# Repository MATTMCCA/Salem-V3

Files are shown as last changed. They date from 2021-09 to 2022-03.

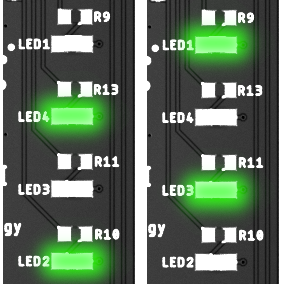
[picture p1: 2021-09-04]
Manual/masters/pics/error_state.png

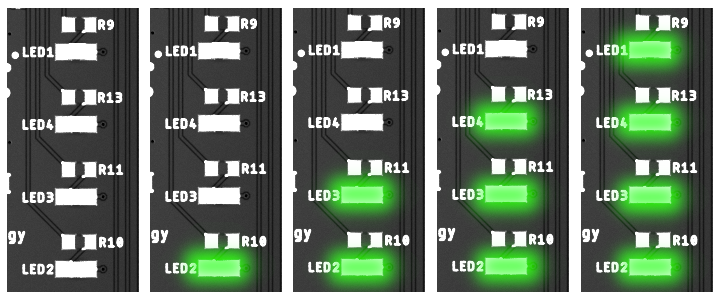
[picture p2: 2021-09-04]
Manual/masters/pics/led_bat.png

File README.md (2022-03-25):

# Salem Version 3

Third Revision of Salem, Capacitive Proximity Sensor.

https://youtu.be/Kz70OKQegTU

---

### Salem was originally designed as a REM Pod competitor. A conscience and lack of follow-though drove me to release the project, for the betterment of *Parapsychology Research*.

(Plus I didn't feel like dealing with *FCC Regulatory Compliance*.... or shipping logistics, customers, pricing, manufacturing, overhead... )

Effective range, depending on placement can vary from 6-10 inches. This is a ballpark estimate from lab testing. I have not had time to carry out a conclusive test to gauge the effective sensing range.

---

### Info

This project is a battery powered capacitive proximity sensor. Some folks believe a device like this will detect paranormal apparitions. **I can not confirm or deny the existence of ghosts. I am also not claiming this device will detect paranormal apparitions, this includes but is not limited too.**

- The Jersey Devil
- The Headless Body of Spiro Agnew
- Ghost
- Demons / Angles
- Batman
- Karma
- UFO's / USO's
- The Chupacabra
- Vampires
- Witches / Wizards
- The SOB that ate my Twix
- Bigfoot / Yeti's
- Tom Cruise
- Most Breads of Cats.
- Bloody Mary
- Unicorns
- Other Benign and Nefarious Mythical Creatures

However devices like this do exist on the market, and consumers use them in an effort to detect the "paranormal".

In full transparency, both the hardware and firmware are included in this repo. Should an individual wish to understand the operation of this device and similar devices, all necessary information is provided.

### Operation Note:

[Further Readings A](https://www.allaboutcircuits.com/technical-articles/introduction-to-capacitive-touch-sensing)

[Further Readings B](https://www.clippercontrols.com/pages/Dielectric-Constant-Values.html)

**I offer no support for this device, it has become a leisurely project.**

---

This project has been added to the hackaday [halloween hackfest](https://hackaday.com/2021/08/10/new-contest-halloween-hackfest/)

### Borrowed works maintain original license.

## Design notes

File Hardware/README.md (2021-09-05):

# Hardware Assembly 

The following items were purchased to aid in physical assembly.

- [Mounting Tape](https://www.amazon.com/gp/product/B0888DKR92)
- [Stainless Steel Internal Tooth Star Lock Washers](https://www.amazon.com/gp/product/B0794YF3QP/)
- [M3 Stainless Steel 304 Hex Socket Head Cap Bolt](https://www.amazon.com/gp/product/B07VNDFYNQ/)

## Assembly Notes

- `40mm` of `0.5mm x 24mm` mounting tape was used to adhere the battery pack onto the PCB before soldering the battery pack leads.
- `1 M3, lock washer` was placed on the antenna pad
- `1 M3, 5mm bolt` was passed though the lock washer, though the PCB, and screwed into the taped `M3 antenna`.

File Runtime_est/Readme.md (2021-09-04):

# Battery Life

| State | Current Draw | Supply voltage  |
| --- | --- | --- |
| Active | 4.38mA | 3.3v |
| Idle | 0.53mA | 3.3v |

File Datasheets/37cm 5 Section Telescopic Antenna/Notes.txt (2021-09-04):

1Pc 37cm 5 Section Telescopic Stainless Steel AM FM Radio Universal Antenna

Product Name : Telescopic Antenna;
Sections : 5 Sections
Unstretched Size : 105mm ";
Full Length : 354mm
Hole Diameter : 3mm
Material : Stainless Steel, Brass;Color : Silver Tone
4 sections telescopic antenna aerial.

Mainly used in television, radio, electric toy, remote control, lamps and lanterns, 
VCD, and other special configuration communications antenna and iron and tools 
antenna and other electronics products.

Great replacement for your damaged TV antenna or FM radio antenna.

Package Content : 1 x Telescopic Antenna

Note:
Light shooting and different displays may cause the color of the item in the
 picture a little different from the real thing. The measurement allowed error is +/- 1-3cm.

StoreFront: https://www.aliexpress.com/item/1005002545144839.html

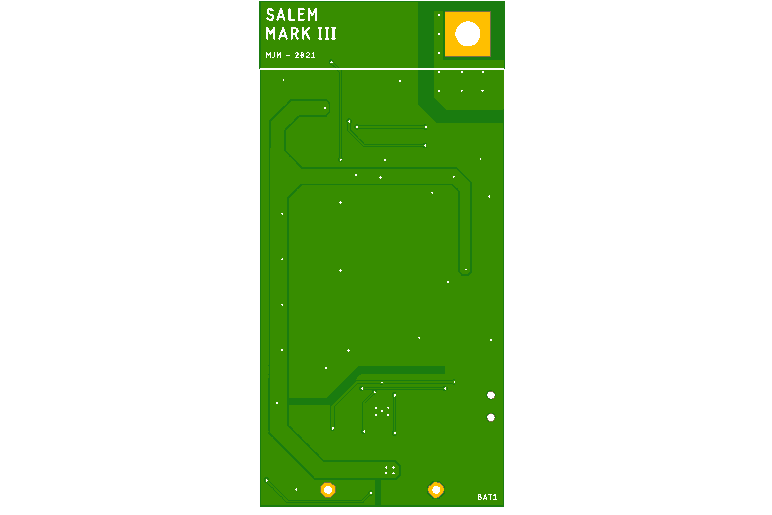
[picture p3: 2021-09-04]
Hardware/SV3/board/SV3_bot.png

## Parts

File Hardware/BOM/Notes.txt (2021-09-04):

See Digikey List for a more comprehensive PartsList.

Currently Private

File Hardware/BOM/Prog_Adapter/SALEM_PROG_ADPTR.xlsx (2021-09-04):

Index | Manufacturer Part Number | Manufacturer Name | Description | Availability | Stock Status | Customer Reference | Reference Designator | Requested Quantity 1 | Pack Quantity 1 | Pack Type 1 | Digi-Key Part Number 1 | Unit Price 1 | Extended Price 1 | Minimum Order Quantity 1 | Requested Part Number | Part Status | Original Part numbers
1 | 0532610671 | Molex | CONN HEADER SMD R/A 6POS 1.25MM | 28,644 | In Stock | PROG |  | 1 | 1 | Cut Tape (CT) | WM7624CT-ND | 0.74000 | $0.74 | 1 | WM7624CT-ND | Active | WM7624CT-ND
2 | SFH11-PBPC-D10-ST-BK | Sullins Connector Solutions | CONN HDR 20POS 0.1 GOLD PCB | 34,922 | In Stock | J1 |  | 1 | 1 | Tray | S9197-ND | 1.15000 | $1.15 | 1 | S9197-ND | Active | S9197-ND
3 | 0151340602 | Molex | PICOBLADE 6 CIRCUIT 150MM | 961 | In Stock |  |  | 1 | 1 | Bag | WM15266-ND | 4.69000 | $4.69 | 1 | WM15266-ND | Active | WM15266-ND

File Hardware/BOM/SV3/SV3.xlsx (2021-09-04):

Index | Manufacturer Part Number | Manufacturer Name | Description | Availability | Customer Reference | Reference Designator | Requested Quantity 1 | Pack Quantity 1 | Pack Type 1 | Digi-Key Part Number 1 | Unit Price 1 | Extended Price 1 | Minimum Order Quantity 1 | Requested Part Number | Part Status | Original Part numbers | LCSC
1 | 0532610671 | Molex | CONN HEADER SMD R/A 6POS 1.25MM | 64,807 In Stock | PROG1 | PROG1 | 1 | 1 | Cut Tape (CT) | WM7624CT-ND | 0.74000 | $0.74 | 1 | WM7624CT-ND | Active | WM7624CT-ND
2 | 2462RB | Keystone Electronics | BATTERY HOLDER AA 2 CELL PC PIN | 1,637 In Stock | BAT1 | BAT1 | 1 | 1 | Bulk | 36-2462RB-ND | 1.62000 | $1.62 | 1 | 36-2462RB-ND | Active | 36-2462RB-ND
3 | 150080VS75000 | Würth Elektronik | LED GREEN CLEAR 0805 SMD | 20,979 In Stock | LED1, LED2, LED3, LED4 | LED1, LED2, LED3, LED4 | 4 | 4 | Cut Tape (CT) | 732-4986-1-ND | 0.18000 | $0.72 | 1 | 732-4986-1-ND | Active | 732-4986-1-ND | C98224
4 | RNCP0603FTD100R | Stackpole Electronics Inc | RES 100 OHM 1% 1/8W 0603 | 191,979 In Stock | R3 | R3 | 1 | 1 | Cut Tape (CT) | RNCP0603FTD100RCT-ND | 0.10000 | $0.10 | 1 | RNCP0603FTD100RCT-ND | Active | RNCP0603FTD100RCT-ND
5 | RMCF0603FG100K | Stackpole Electronics Inc | RES 100K OHM 1% 1/10W 0603 | 430,442 In Stock | R1, R2, R4, R6, R12 | R1, R2, R4, R6, R12 | 5 | 5 | Cut Tape (CT) | RMCF0603FG100KCT-ND | 0.10000 | $0.50 | 1 | RMCF0603FG100KCT-ND | Active | RMCF0603FG100KCT-ND
6 | C0603C104K5RACTU | KEMET | CAP CER 0.1UF 50V X7R 0603 | 4,471,170 In Stock | C1, C2, C4, C5, C6, C10, C11, C12, C13, C14 | C1, C2, C4, C5, C6, C10, C11, C12, C13, C14 | 10 | 10 | Cut Tape (CT) | 399-5089-1-ND | 0.08900 | $0.89 | 1 | 399-5089-1-ND | Active | 399-7845-1-ND
7 | RMCF0603JG10K0 | Stackpole Electronics Inc | RES 10K OHM 5% 1/10W 0603 | 857 In Stock | R7, R8 | R7, R8 | 2 | 2 | Cut Tape (CT) | RMCF0603JG10K0CT-ND | 0.10000 | $0.20 | 1 | RMCF0603JG10K0CT-ND | Active | RMCF0603JT10K0CT-ND
8 | TMK212BBJ106MG-T | Taiyo Yuden | CAP CER 10UF 25V X5R 0805 | 170,875 In Stock | C3, C7, C8 | C3, C7, C8 | 3 | 3 | Cut Tape (CT) | 587-6025-1-ND | 0.21000 | $0.63 | 1 | 587-6025-1-ND | Active | 399-C0805C106K4PAC7210CT-ND
9 | C0603C105K3RACTU | KEMET | CAP CER 1UF 25V X7R 0603 | 111,277 In Stock | C9 | C9 | 1 | 1 | Cut Tape (CT) | 399-7376-1-ND | 0.28000 | $0.28 | 1 | 399-7376-1-ND | Active | 399-11133-1-ND
10 | LQH2HPZ2R2MJRL | Murata Electronics | FIXED IND 2.2UH 1.65A 110.4 MOHM | 1,581 In Stock | L1 | L1 | 1 | 1 | Cut Tape (CT) | 490-15899-1-ND | 0.46000 | $0.46 | 1 | 490-15899-1-ND | Active | 490-15899-1-ND | C1331117
11 | FDLL4148 | ON Semiconductor | DIODE GEN PURP 100V 200MA SOD80 | 81,956 In Stock | D1 | D1 | 1 | 1 | Cut Tape (CT) | FDLL4148CT-ND | 0.11000 | $0.11 | 1 | FDLL4148CT-ND | Active | FDLL4148CT-ND | C78608
12 | RMCF0603JT6K80 | Stackpole Electronics Inc | RES 6.8K OHM 5% 1/10W 0603 | 143,615 In Stock | R5 | R5 | 1 | 1 | Cut Tape (CT) | RMCF0603JT6K80CT-ND | 0.10000 | $0.10 | 1 | RMCF0603JT6K80CT-ND | Active | RMCF0603JT6K80CT-ND
13 | RMCF0603FT649R | Stackpole Electronics Inc | RES 649 OHM 1% 1/10W 0603 | 26,030 In Stock | R9, R10, R11, R13 | R9, R10, R11, R13 | 4 | 4 | Cut Tape (CT) | RMCF0603FT649RCT-ND | 0.10000 | $0.40 | 1 | RMCF0603FT649RCT-ND | Active | RMCF0603FT649RCT-ND
14 | AP7215-33YG-13 | Diodes Incorporated | IC REG LINEAR 3.3V 600MA SOT89-3 | 4,379 In Stock | U4 | U4 | 1 | 1 | Cut Tape (CT) | AP7215-33YG-13DICT-ND | 0.51000 | $0.51 | 1 | AP7215-33YG-13DICT-ND | Active | AP7215-33YG-13DICT-ND | C460367
15 | SBC817-40LT1G | ON Semiconductor | TRANS NPN 45V 500MA SOT23-3 | 15,236 In Stock | T1 | T1 | 1 | 1 | Cut Tape (CT) | SBC817-40LT1GOSCT-ND | 0.28000 | $0.28 | 1 | SBC817-40LT1GOSCT-ND | Active | BC817-40LT3GOSCT-ND | C604682
16 | CSS-0575A-SMT-TR | CUI Devices | AUDIO MAGNETIC XDCR 2-4V SMD | 30,191 In Stock | LS1 | LS1 | 1 | 1 | Cut Tape (CT) | 102-2201-1-ND | 2.62000 | $2.62 | 1 | 102-2201-1-ND | Active | 102-2201-1-ND | C94598
17 | FDC1004QDGSRQ1 | Texas Instruments | IC CAPACITIVE SENSING 4CH 10VSSO | 1,202 In Stock | U2 | U2 | 1 | 1 | Cut Tape (CT) | 296-42334-1-ND | 6.55000 | $6.55 | 1 | 296-42334-1-ND | Active | 296-42334-1-ND | C2652097
18 | PCM12SMTR | C&K | SWITCH SLIDE SPDT 300MA 6V | 51,180 In Stock | SW3 | SW3 | 1 | 1 | Cut Tape (CT) | 401-2016-1-ND | 0.92000 | $0.92 | 1 | 401-2016-1-ND | Active | 401-2016-1-ND | C221841
19 | PTS 647 SN50 SMTR2 LFS | C&K | TACT 4.5 X 4.5, 5.0 MM H, 1.0N, | 633 In Stock | SW1, SW2 | SW1, SW2 | 2 | 2 | Cut Tape (CT) | PTS647SN50SMTR2LFSCT-ND | 0.13000 | $0.26 | 1 | PTS647SN50SMTR2LFSCT-ND | Active | PTS647SN50SMTR2LFSCT-ND | C2799414
20 | STM32L071KBT6 | STMicroelectronics | IC MCU 32BIT 128KB FLASH 32LQFP | 1,404 In Stock | U1 | U1 | 1 | 1 | Tray | 497-18577-ND | 5.07000 | $5.07 | 1 | 497-18577-ND | Active | 497-18577-ND | C2055281
21 | TPS61202DRCT | Texas Instruments | IC REG BOOST 5V 1.2A 10VSON | 0 In Stock | U3 | U3 | 1 | 1 | Cut Tape (CT) | 296-21685-1-ND | 2.85000 | $2.85 | 1 | 296-21685-1-ND | Active | 296-21685-1-ND | C2070658

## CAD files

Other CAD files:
Render/3D/SV3 v5.f3d

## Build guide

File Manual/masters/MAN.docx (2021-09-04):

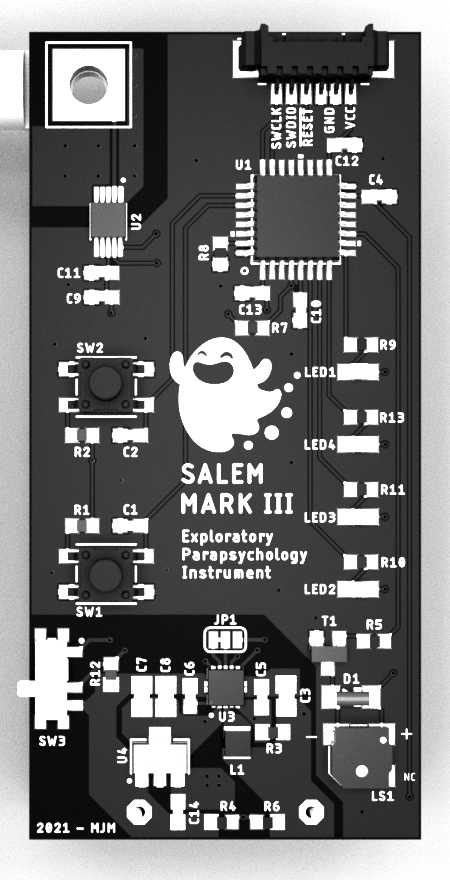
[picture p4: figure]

Salem Exploratory Parapsychology Instrument

Operating Characteristics:

Nominal voltage: 3.0V

Current Draw: 0.55mA – 4.55mA

Battery type: 2X AA [1.5V]

Alkaline batteries recommended for best result

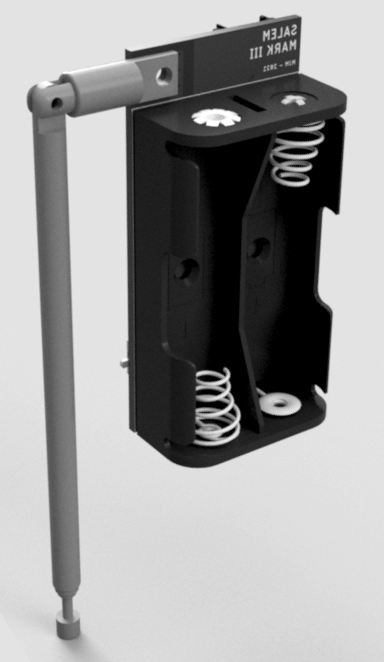
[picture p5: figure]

Before Operating the Device

Hardware V3

Warning: This device has no reverse polarity protection, please insert the batteries correctly.

- Place the batteries into the device’s battery pack, please ensure the batteries are new.
- Allow the device to acclimate to the rooms ambient temperature to ensure an accurate reading during initialization.
- Extend the antenna to its maximum height.
- Place the device away from objects to avoid false readings.

Powering your Device on for the first time

Initialization Sequence:

Once the device is setup, power on the device. When power is first applied, the indicator lights will cycle up then back down. Following this light sequence, the battery level will be displayed.

Battery Check:

The voltage of the battery will be displayed via the indicators. The minimum operating voltage of the device is 1.8v. Batteries providing less than 1.8v will cause the device to report an error. This is to ensure the device has a stable voltage source for reliable operation.


Baseline Calibration:

After the Battery check is complete, the device will take 100 samples of the environment to use as the “baseline”. This baseline will be what following measurements are compared against. It is very important that the device be free of interference during this time. Please take a few steps back from the device while it is taking the baseline reading.

Once the device has sufficient environmental data, a tone will sound. This indicates the device is now ready for field operation.

Adjusting the Sensitivity Threshold

After the device has completed the initialization sequence, you may choose to adjust the sensitivity threshold. This can be done with the up/down buttons. Pressing the buttons will result in a tone, holding the button will make multiple steps until the button is released.

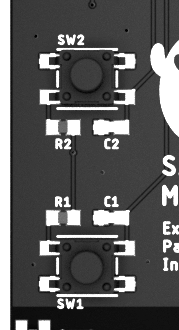
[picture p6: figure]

The UP button, raises the sensitivity threshold, Decreasing the devices sensitivity.

The DOWN button, lowers the sensitivity threshold, Increasing the devices sensitivity.

Active Temperature Compensation

Due to the nature of the device, fluctuations in temperature will affect the devices readings. To combat this, the device will actively adjust the baseline during idle state IF there is a measurable change in ambient temperature.

A correction due to temperature shift will result in the device sounding a tone. A tone with increasing pitch will denote a positive temperature shift. A tone with decreasing pitch will denote a negative temperature shift.

Reading the Devices Indicators

During normal operation the indicators will display proximity strength with respect to the baseline. In addition to the visual indicators, audible tones will also be present. The tones will increase / decrease in pitch based on proximity strength. There are a total of 11 intensity steps that will be reflected on the device’s indicators.

Error State

if at any point during the device’s operation a system check fails, the device will jump into an error state. This error state will be realized by flashing indicators.


Troubleshooting

- The most common cause of an error state is “low battery”. This can be rectified by powering off the device, replacing the batteries, and powering the device on again.
- If there is an internal error, cycling the power should resolve the error states.
- If there is any damage to the device physically, the error state may have no resolution.

Programming Header

The programming header is meant for factory programming. Should an update scheme be realized, this programming header will be used for updating the device.

Loading unauthorized firmware is possible, but not recommended. Any damage to the device as a result of curiosity is the user’s responsibility.

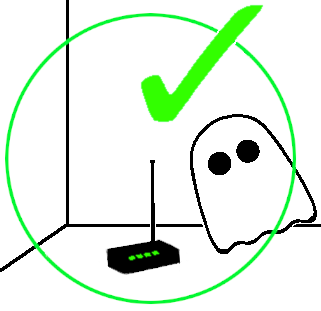
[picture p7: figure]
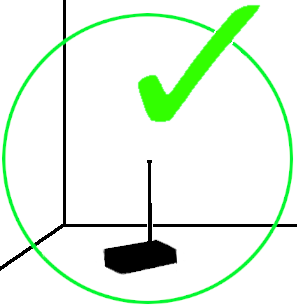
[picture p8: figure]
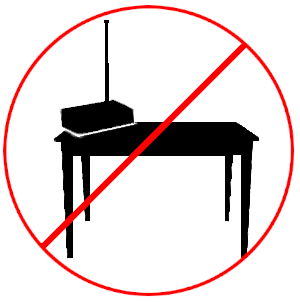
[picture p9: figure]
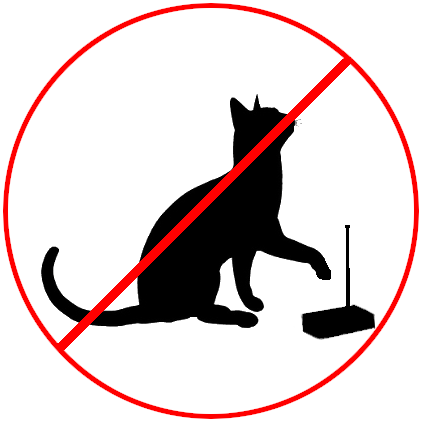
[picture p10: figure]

Recommended Operating Scenarios

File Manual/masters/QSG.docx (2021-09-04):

Salem Exploratory Parapsychology Instrument

Quick Start

1.) Acclimate the device to the room’s ambient temperature.
2.) Place the device on a smooth level surface and extend the antenna
3.) Power on the device and step out of the detection zone.
4.) Wait for the initialization sequence to complete (chirp).
5.) Adjust the sensitivity threshold as needed (up / down).

Antenna

Programing Header

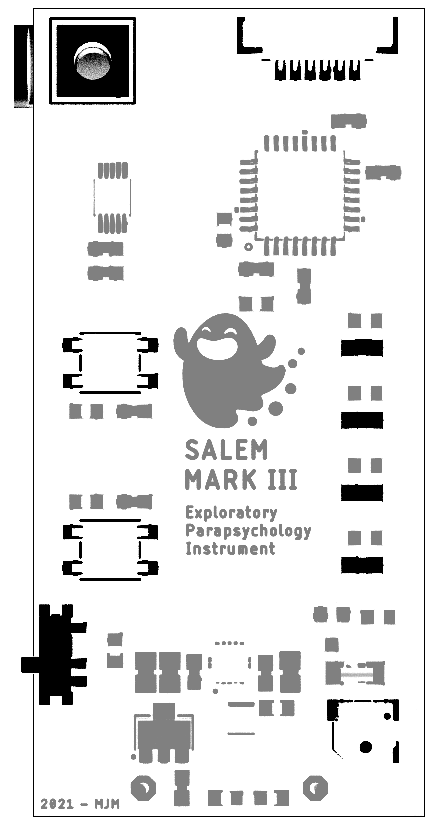
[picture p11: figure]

Button [UP]

LED Indicators

Button [DOWN]

Speaker

Power Switch

Hardware Version 3

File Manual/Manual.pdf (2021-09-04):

## Salem Exploratory Parapsychology Instrument

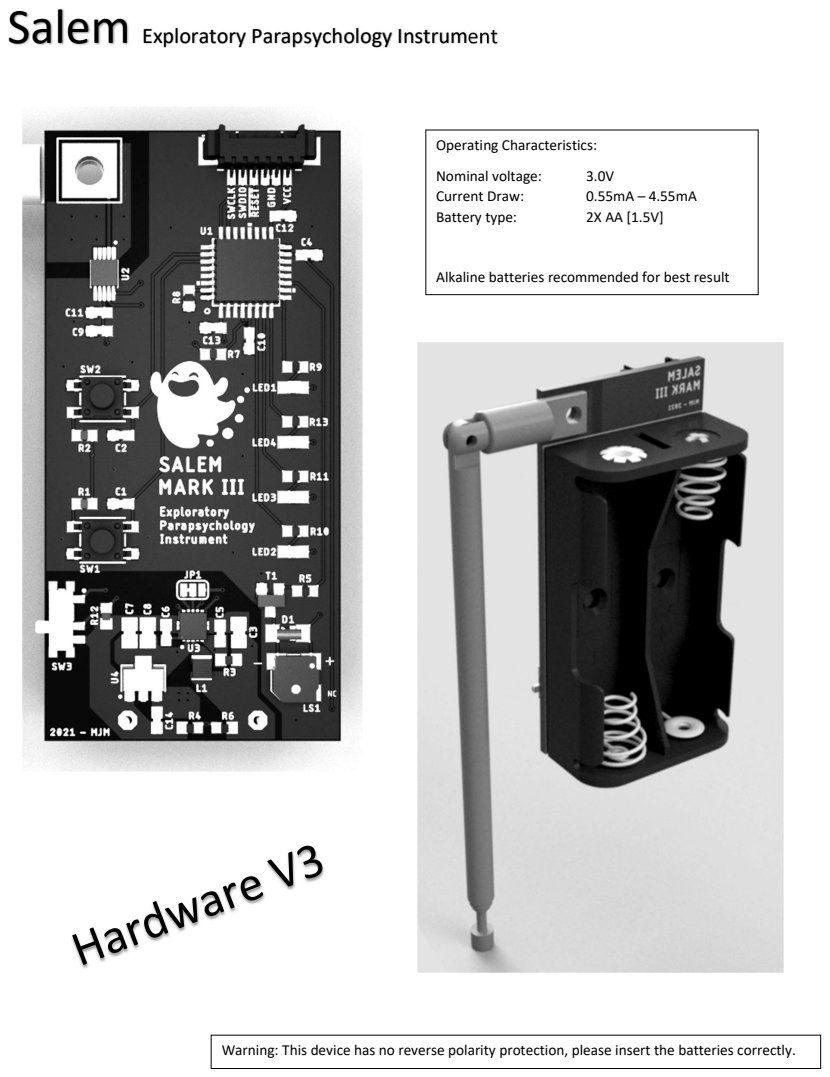
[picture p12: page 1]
Operating Characteristics:; Nominal voltage:; Current Draw:; Battery type:

Alkaline batteries recommended for best result

Warning: This device has no reverse polarity protection, please insert the batteries correctly.

Before Operating the Device
- Place the batteries into the device’s battery pack, please ensure the batteries are new.
- Allow the device to acclimate to the rooms ambient temperature to ensure an accurate reading during initialization.
- Extend the antenna to its maximum height.
- Place the device away from objects to avoid false readings.

Powering your Device on for the first time
Initialization Sequence:
Once the device is setup, power on the device. When power is first applied, the indicator lights will cycle up then back down. Following this light sequence, the battery level will be displayed.

Battery Check:
The voltage of the battery will be displayed via the indicators. The minimum operating voltage of the device is 1.8v. Batteries providing less than 1.8v will cause the device to report an error. This is to ensure the device has a stable voltage source for reliable operation.

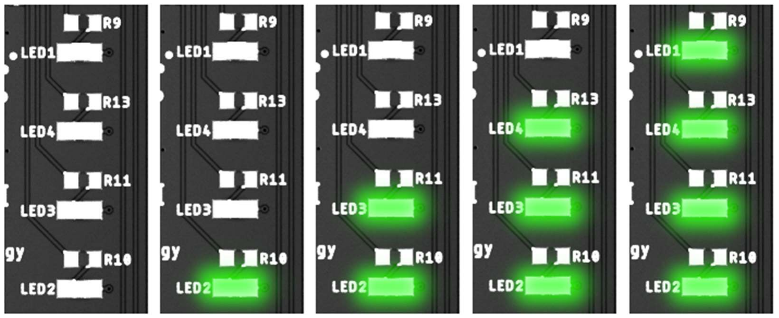
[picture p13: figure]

Baseline Calibration:
After the Battery check is complete, the device will take 100 samples of the environment to use as the “baseline”. This baseline will be what following measurements are compared against. It is very important that the device be free of interference during this time. Please take a few steps back from the device while it is taking the baseline reading.
Once the device has sufficient environmental data, a tone will sound. This indicates the device is now ready for field operation.

Adjusting the Sensitivity Threshold
After the device has completed the initialization sequence, you may choose to adjust the sensitivity threshold. This can be done with the up/down buttons. Pressing the buttons will result in a tone, holding the button will make multiple steps until the button is released.

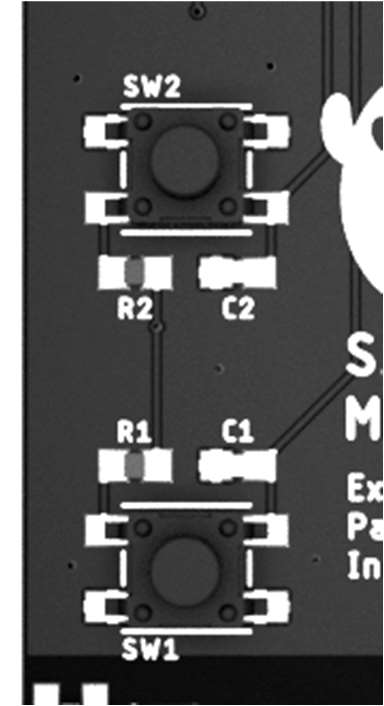
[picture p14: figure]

Active Temperature Compensation
Due to the nature of the device, fluctuations in temperature will affect the devices readings. To combat this, the device will actively adjust the baseline during idle state IF there is a measurable change in ambient temperature.
A correction due to temperature shift will result in the device sounding a tone. A tone with increasing pitch will denote a positive temperature shift. A tone with decreasing pitch will denote a negative temperature shift.

Reading the Devices Indicators
During normal operation the indicators will display proximity strength with respect to the baseline. In addition to the visual indicators, audible tones will also be present. The tones will increase / decrease in pitch based on proximity strength. There are a total of 11 intensity steps that will be reflected on the device’s indicators.

### The UP button, raises the sensitivity threshold, Decreasing the devices

sensitivity.

### The DOWN button, lowers the sensitivity threshold, Increasing the

devices sensitivity.

Error State
if at any point during the device’s operation a system check fails, the device will jump into an error state. This error state will be realized by flashing indicators.

Troubleshooting

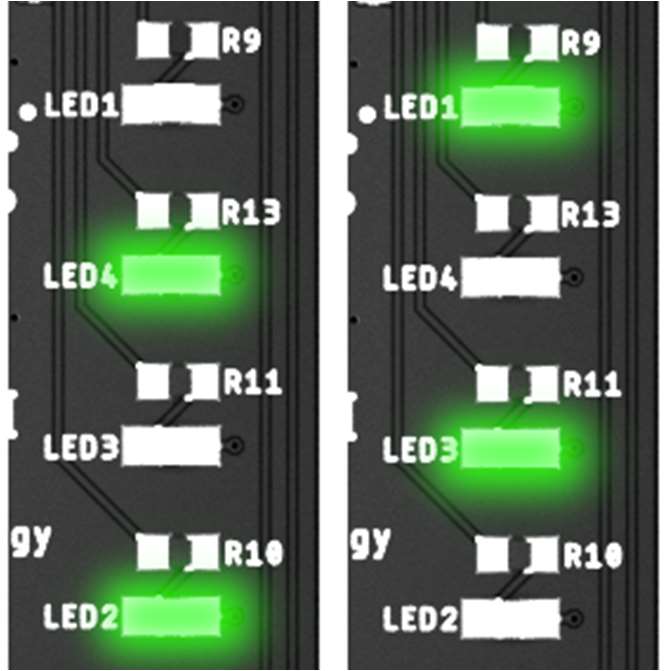
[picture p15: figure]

- The most common cause of an error state is “low battery”. This can be rectified by powering off the device, replacing the batteries, and powering the device on again.
- If there is an internal error, cycling the power should resolve the error states.
- If there is any damage to the device physically, the error state may have no resolution.

Programming Header
The programming header is meant for factory programming. Should an update scheme be realized, this programming header will be used for updating the device.
Loading unauthorized firmware is possible, but not recommended. Any damage to the device as a result of curiosity is the user’s responsibility.

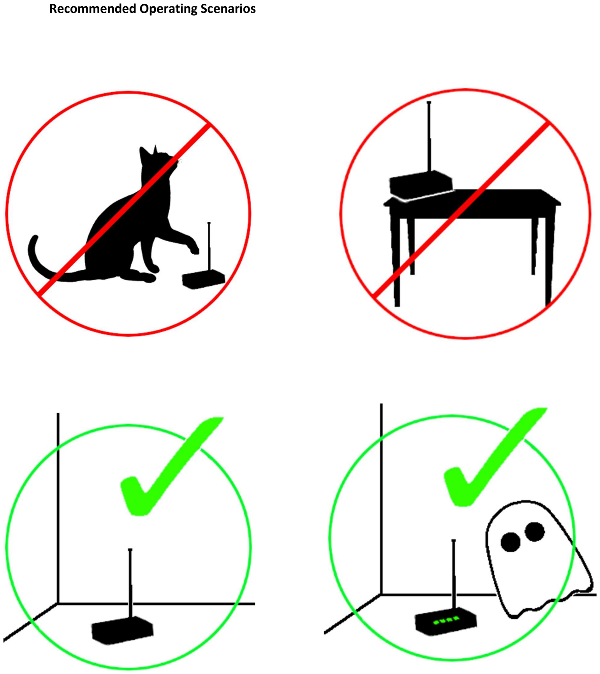
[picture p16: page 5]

Recommended Operating Scenarios

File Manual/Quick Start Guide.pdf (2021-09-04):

## Quick Start

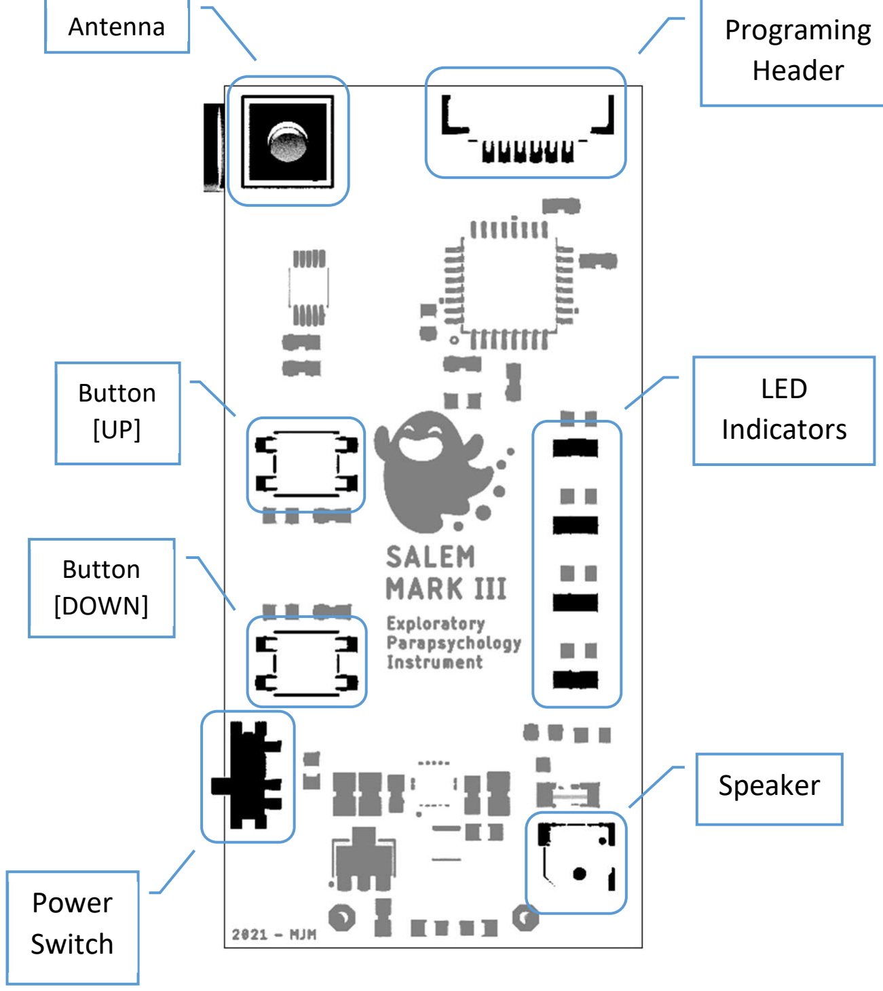
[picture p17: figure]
LED Indicators; Programing Header; Antenna; Button [UP]; Button [DOWN]; Power Switch; Speaker

1.) Acclimate the device to the room’s ambient temperature.

2.) Place the device on a smooth level surface and extend the antenna

3.) Power on the device and step out of the detection zone.

4.) Wait for the initialization sequence to complete (chirp).

5.) Adjust the sensitivity threshold as needed (up / down).

Salem Exploratory Parapsychology Instrument

Hardware Version 3

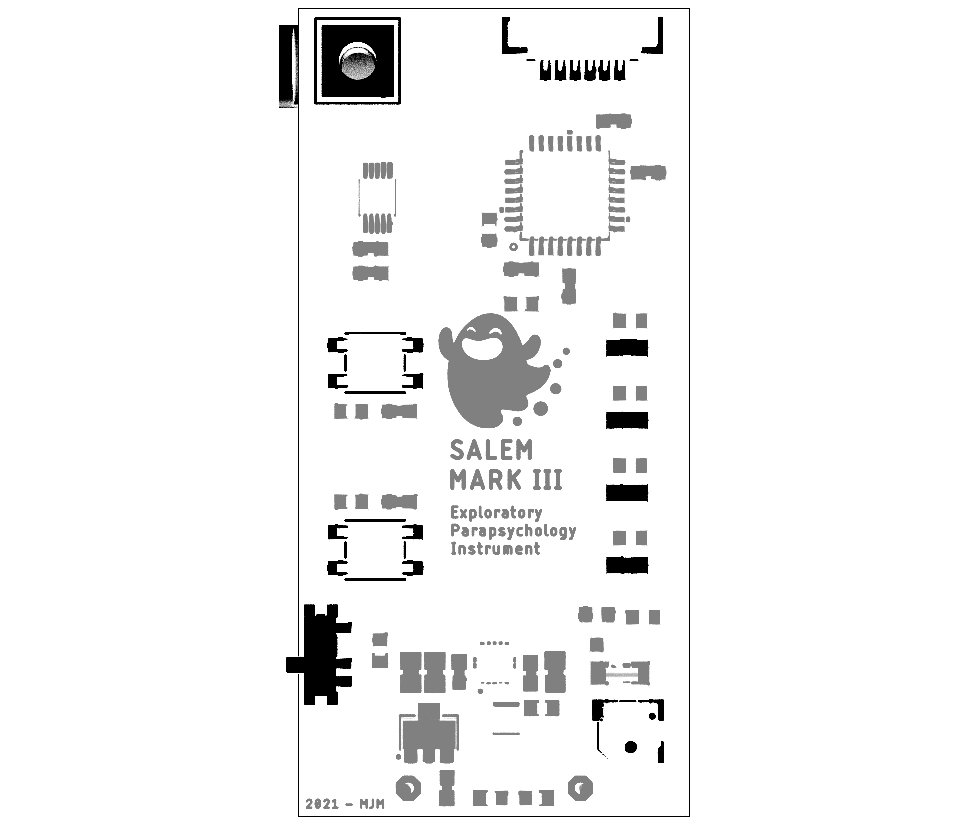
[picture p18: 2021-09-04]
Manual/masters/pics/sv3_art_2.png

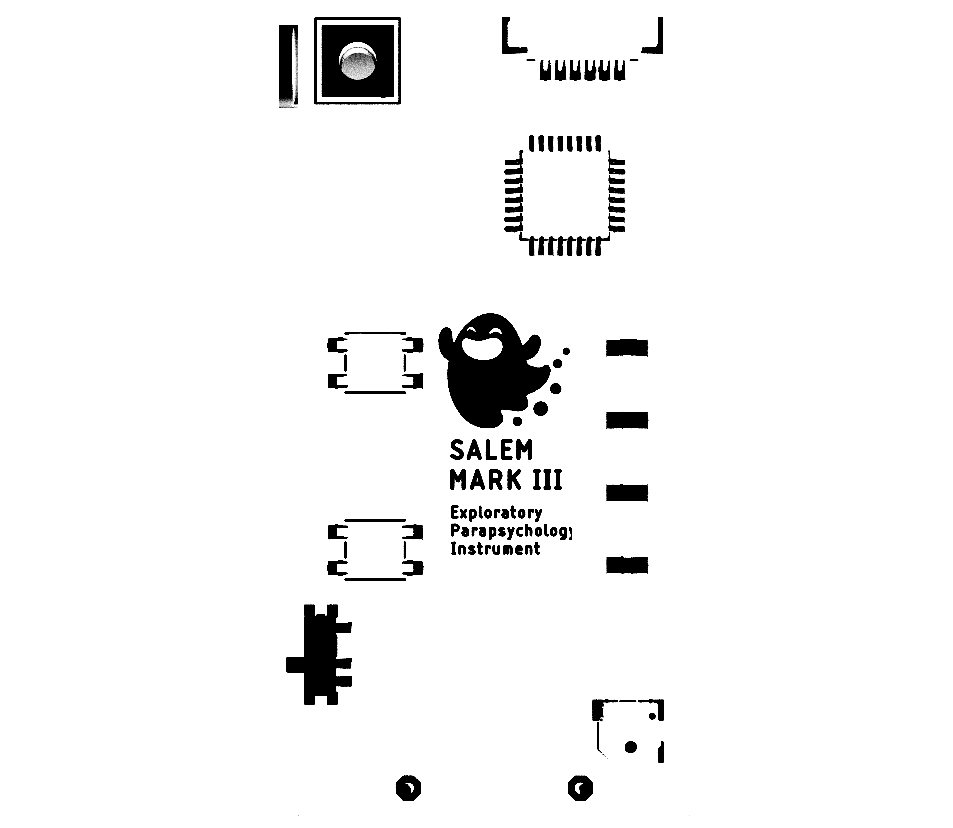
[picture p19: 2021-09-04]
Manual/masters/pics/sv3_art.png

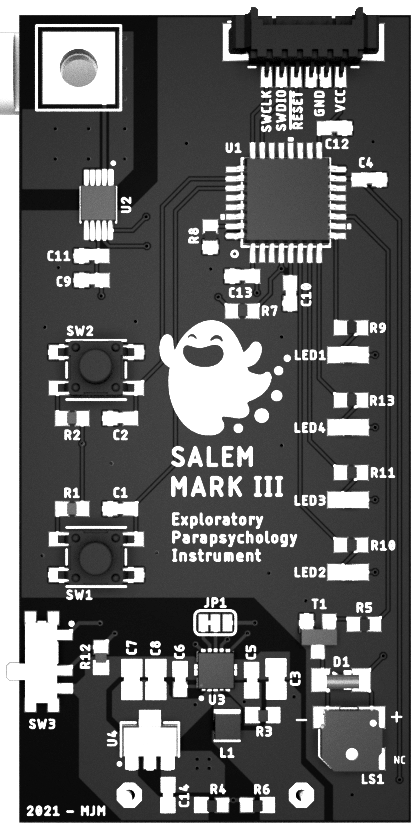
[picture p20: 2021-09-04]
Manual/masters/pics/SV3_v4_bw_crop.png

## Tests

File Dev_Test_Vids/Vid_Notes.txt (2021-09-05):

Quick operational vids taken with my phone. 
Ambient noise was due to room fan, batteries were brand new. 
Yes, I was in my pajamas, its the weekend. 

Sorry ladies, I'm not single, file a formal complaint with the misses.

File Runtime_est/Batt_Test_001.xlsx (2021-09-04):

Salem Hardware v3, battery life | Date: | Time: | Charge%: | Voltage: | State: | Delta Time: | Delta Volts:
DURACELL MN1500 1.5v LR6 | 2021-08-17 | 10:00pm | 100% | 3.219 | OFF | 0h | 0V
~4000 mAh |  |  |  | 3.104 | ON | 0h | 0V
** OLD FIRMWARE
 | 2021-08-18 | 8:00pm | 75% | 2.721 | OFF | 22h | 0.498V | 22h
 |  |  |  | 2.592 | ON | 22h | 0.512V
 | 2021-08-19 | 8:16pm | 75% | 2.546 | OFF | 24h | 0.175V | 46h
 |  |  |  | 2.365 | ON | 24h | 0.227V
 | 2021-08-20 | 8:30pm | 25% | 2.16 | OFF | 24.5h | 0.386V | 70.5h
 |  |  |  | 2.09-1.87 | ON | 24.5h | 0.465V |  | Voltage sagged below 1.9 while active
 |  |  |  |  |  |  |  |  | End of Test
EST 72H, 3days

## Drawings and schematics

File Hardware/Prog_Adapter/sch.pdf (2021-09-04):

J1

Sheet: ABCD | 1 | 2 | 3 | 4 | 5 | 6 | ABCD 1 | 2 | 3 | 4 | 5 | 6

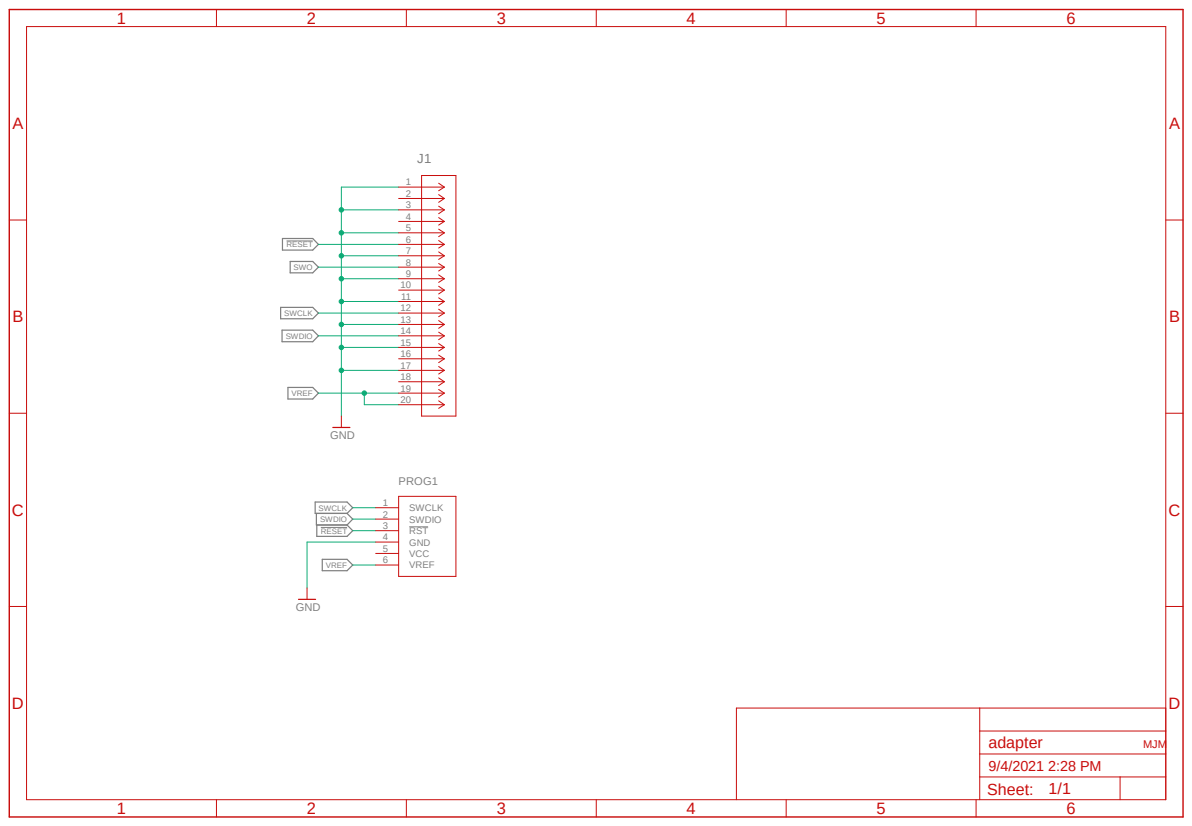
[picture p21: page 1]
GND; SWCLK; SWDIO; RST; VCC; VREF; 6 PROG1; RESET; SWO; MJM; adapter

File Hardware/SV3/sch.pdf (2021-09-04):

PTS | PTS
GND ⁴¹⁴⁸ | +5V +5V

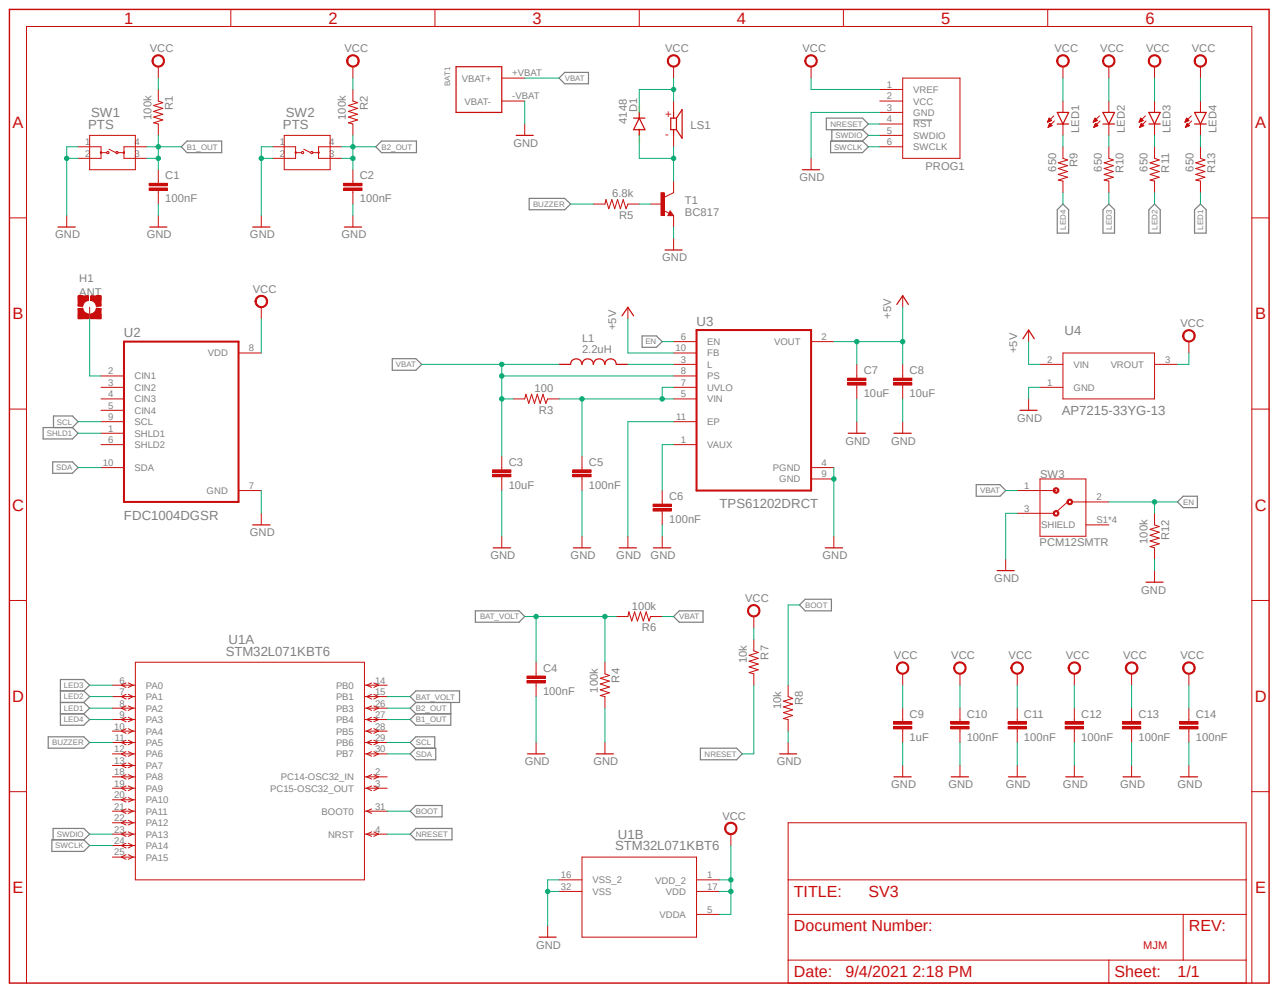
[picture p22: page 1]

Document Number: | REV:

Date: 9/4/2021 2:18 PM | Sheet: 1/1

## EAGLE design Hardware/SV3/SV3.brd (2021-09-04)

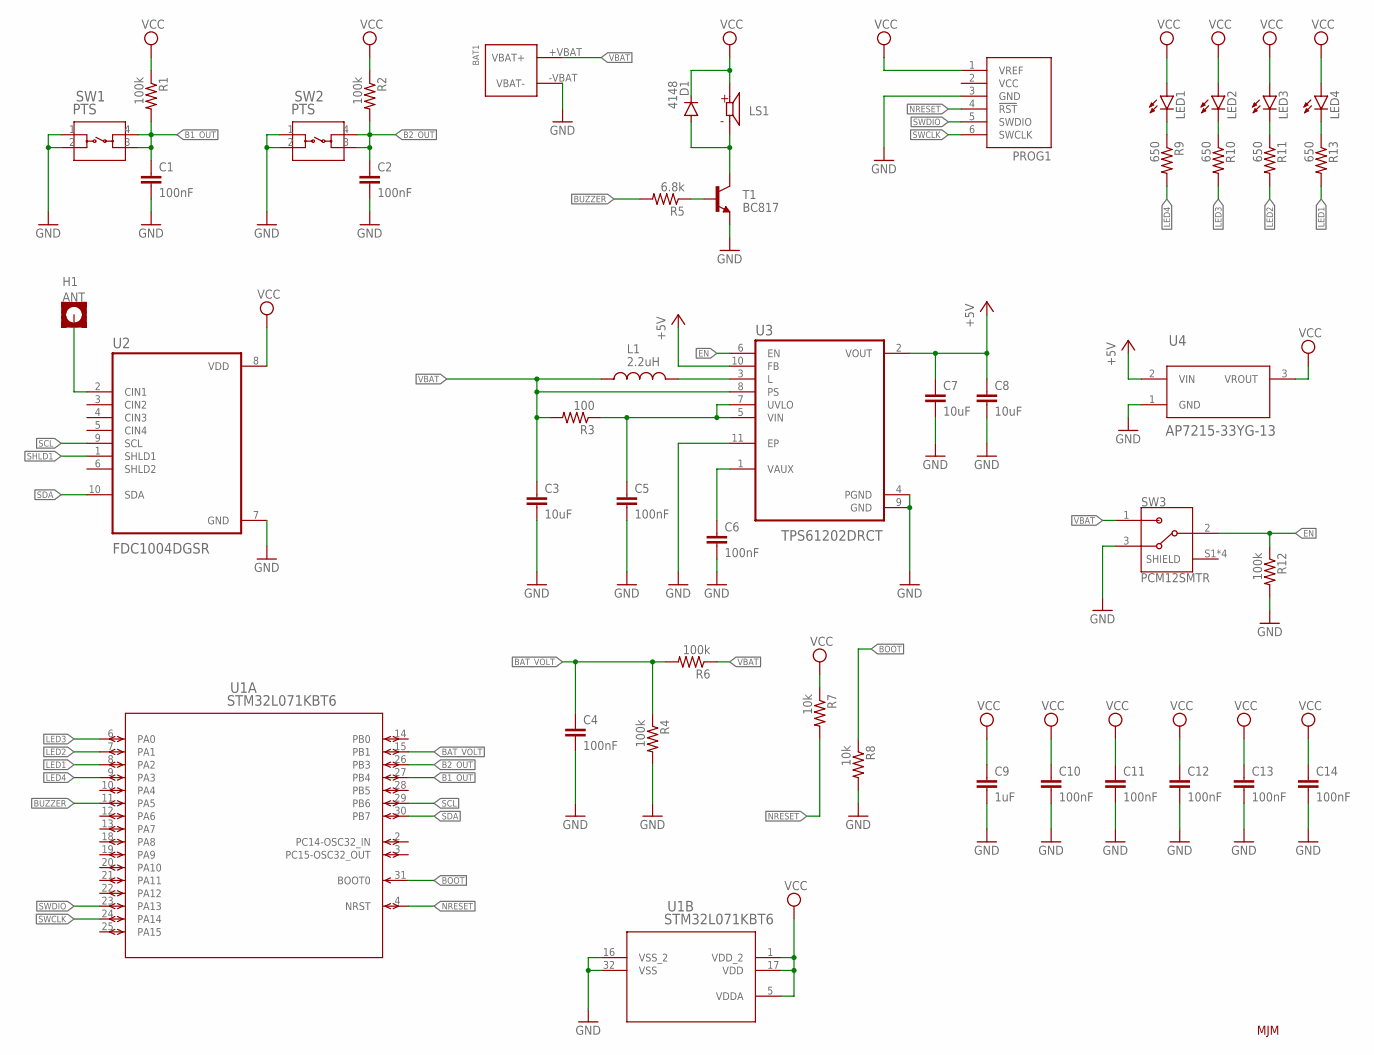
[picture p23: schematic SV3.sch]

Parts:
BAT1: 2462_NO_HOLES; 2462_NO-MOUNTING-HOLES
C1, C2, C4, C5, C6, C10, C11, C12, C13, C14: 100nF; C0603
C3, C7, C8: 10uF; C0805
C9: 1uF; C0603
D1: 4148; SOD80C
H1: ANT; 3,3-PAD-SQUARE
L1: 2.2uH; IND_LQH2HPZ2R2MJRL
LED1, LED2, LED3, LED4: LEDCHIPLED_0805; CHIPLED_0805
LS1: CSS-0575A-SMT; CUI_CSS-0575A-SMT
PROG1: 0532610671
R1, R2, R4, R6, R12: 100k; R0603
R3: 100; R0603
R5: 6.8k; R0603
R7, R8: 10k; R0603
R9, R10, R11, R13: 650; R0603
SW1, SW2: PTS; PTS_647_SN50_SMTR2_LFS-M
SW3: PCM12SMTR; SW_PCM12SMTR
T1: BC817; SOT23-BEC
U1: STM32L071KBT6; LQFP32_7X7X1P4
U2: FDC1004DGSR; SOP50P490X110-10N
U3: TPS61202DRCT; VREG_V62/16624-01YE
U4: AP7215-33YG-13; SOT89-3L_DIO-L

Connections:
+5V: C7.1, C8.1, U3.2 (VOUT), U3.10 (FB), U4.2 (VIN)
B: R5.1, T1.B
B1_OUT: C1.1, R1.2, SW1.3, SW1.4, U1.27 (PB4)
B2_OUT: C2.1, R2.2, SW2.3, SW2.4, U1.26 (PB3)
BAT_VOLT: C4.1, R4.1, R6.2, U1.15 (PB1)
BOOT: R8.1, U1.31 (BOOT0)
BUZZER: R5.2, U1.11 (PA5)
C: D1.A, LS1.2 (N), T1.C
EN: R12.1, SW3.2, U3.6 (EN)
GND: BAT1.-VBAT (VBAT-), C1.2, C2.2, C3.2, C4.2, C5.2, C6.2, C7.2, C8.2, C9.2, C10.2, C11.2, C12.2, C13.2, C14.2, PROG1.3 (GND), R4.2, R8.2, R12.2, SW1.1, SW1.2, SW2.1, SW2.2, SW3.3, T1.E, U1.16 (VSS_2), U1.32 (VSS), U2.7 (GND), U3.4 (PGND), U3.9 (GND), U3.11 (EP), U4.1 (GND)
LED1: R13.2, U1.8 (PA2)
LED2: R11.2, U1.7 (PA1)
LED3: R10.2, U1.6 (PA0)
LED4: R9.2, U1.9 (PA3)
unnamed: H1.B3,3, U2.2 (CIN1)
unnamed: C5.1, R3.1, U3.5 (VIN), U3.7 (UVLO)
unnamed: L1.2, U3.3 (L)
unnamed: C6.1, U3.1 (VAUX)
unnamed: LED1.C, R9.1
unnamed: LED2.C, R10.1
unnamed: LED3.C, R11.1
unnamed: LED4.C, R13.1
NRESET: PROG1.4 (!RST), R7.2, U1.4 (NRST)
SCL: U1.29 (PB6), U2.9 (SCL)
SDA: U1.30 (PB7), U2.10 (SDA)
SHLD1: U2.1 (SHLD1)
SWCLK: PROG1.6 (SWCLK), U1.24 (PA14)
SWDIO: PROG1.5 (SWDIO), U1.23 (PA13)
VBAT: BAT1.+VBAT (VBAT+), C3.1, L1.1, R3.2, R6.1, SW3.1, U3.8 (PS)
VCC: C9.1, C10.1, C11.1, C12.1, C13.1, C14.1, D1.C, LED1.A, LED2.A, LED3.A, LED4.A, LS1.1, PROG1.1 (VREF), R1.1, R2.1, R7.1, U1.1 (VDD_2), U1.5 (VDDA), U1.17 (VDD), U2.8 (VDD), U4.3 (VROUT)

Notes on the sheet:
MJM

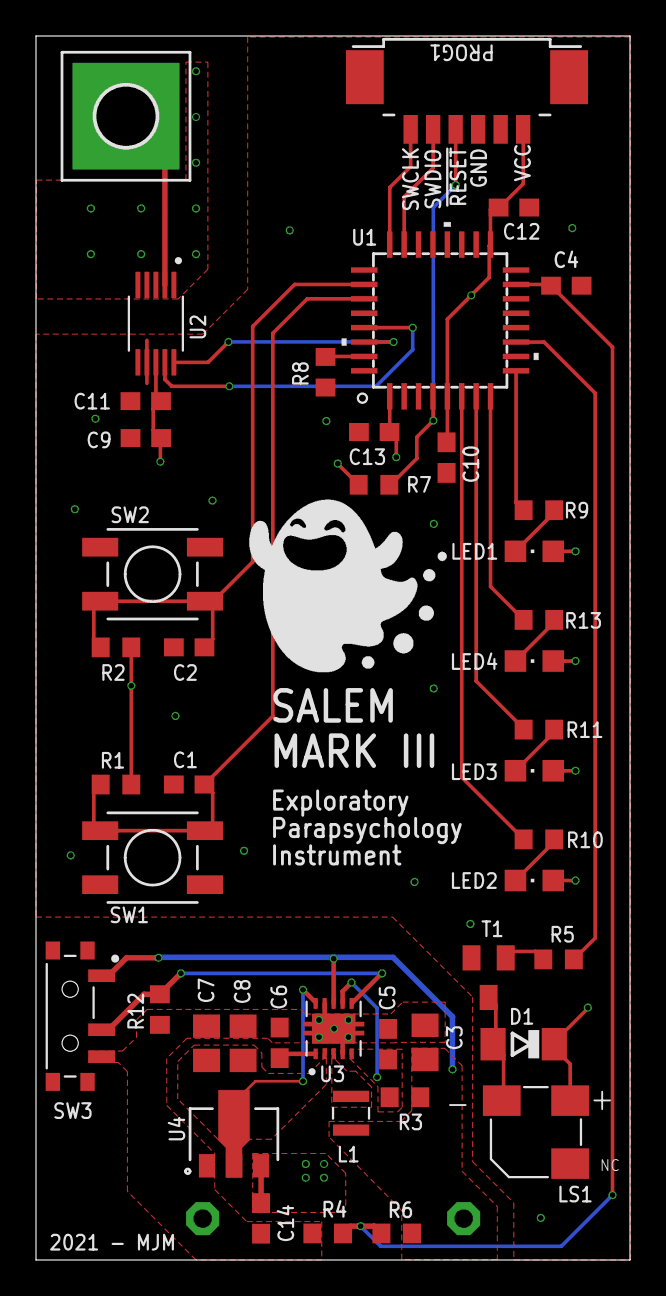
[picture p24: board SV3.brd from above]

Board: 2 copper layers, 33.0 x 68.0 mm, 46 parts (1 on the bottom side), 29 nets.

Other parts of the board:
U$1: GHOST

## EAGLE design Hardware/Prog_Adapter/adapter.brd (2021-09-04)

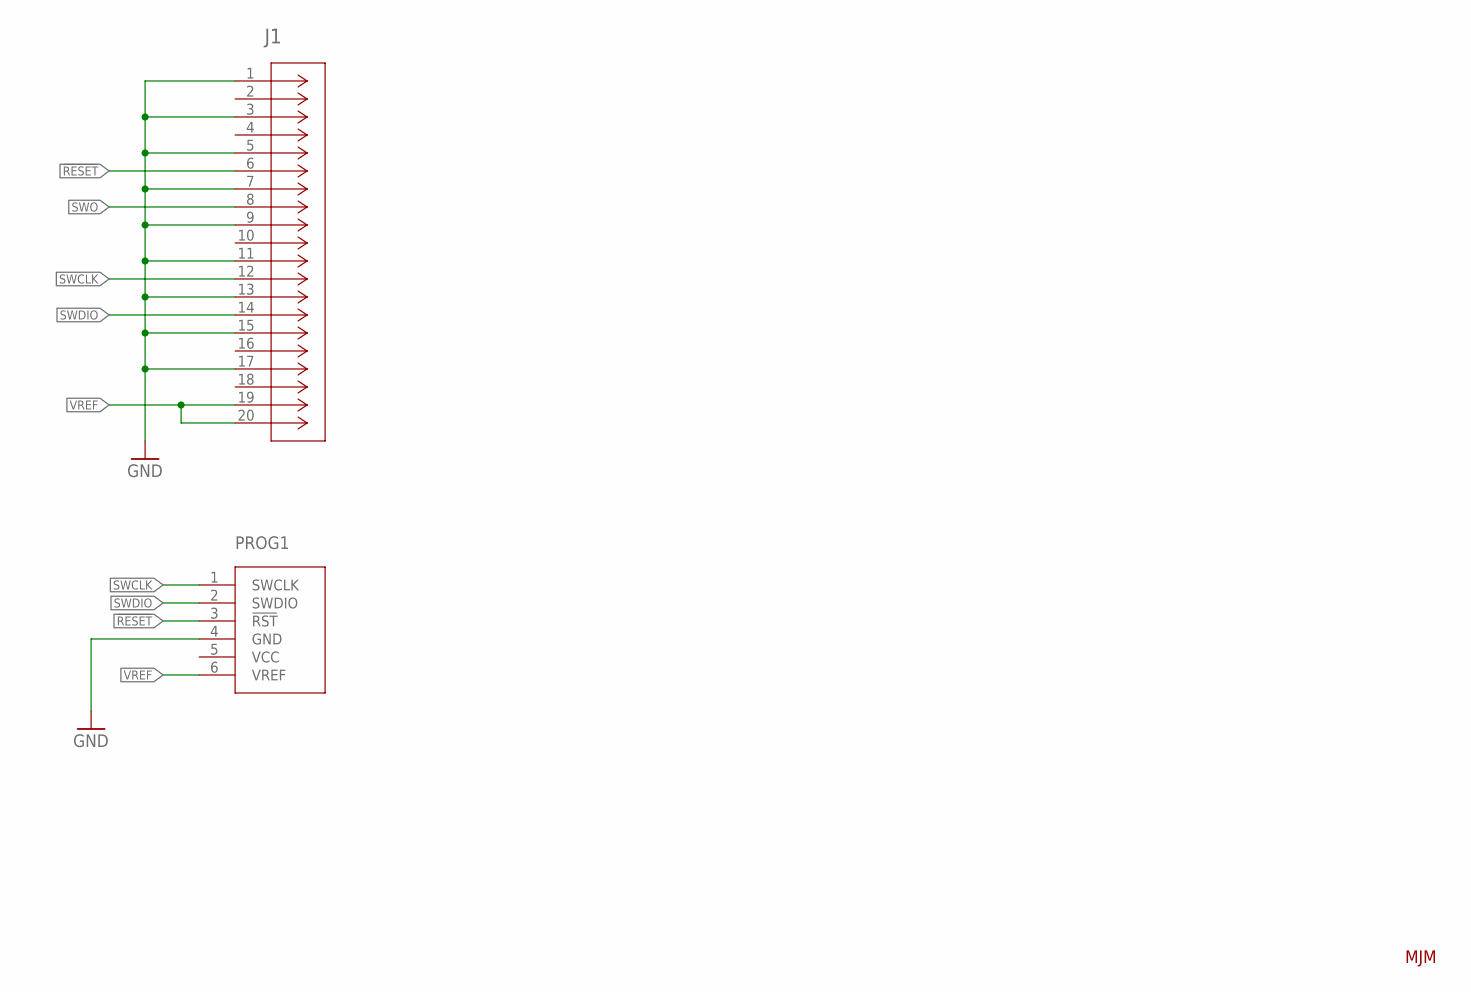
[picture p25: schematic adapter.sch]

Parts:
J1: SFH11-PBPC-D10-ST-BK; CONN_SFH11-PBPC-D10-ST-BK_SUL
PROG1: 0532610671_OP; 0532610671

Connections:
!RESET: J1.6, PROG1.3 (!RST)
GND: J1.1, J1.3, J1.5, J1.7, J1.9, J1.11, J1.13, J1.15, J1.17, PROG1.4 (GND)
SWCLK: J1.12, PROG1.1 (SWCLK)
SWDIO: J1.14, PROG1.2 (SWDIO)
SWO: J1.8
VREF: J1.19, J1.20, PROG1.6 (VREF)

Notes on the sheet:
MJM

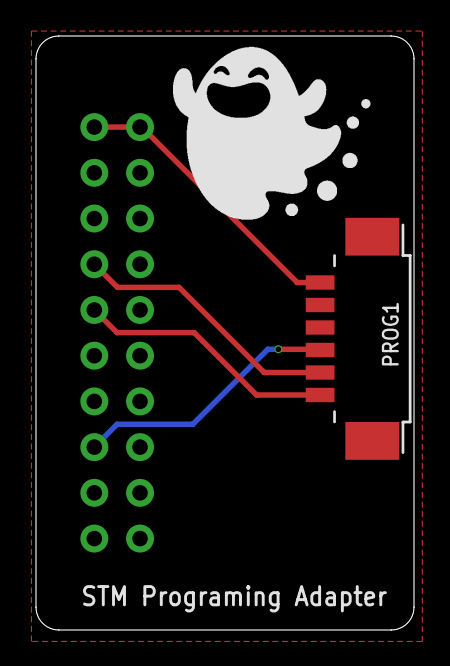
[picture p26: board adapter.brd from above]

Board: 2 copper layers, 21.0 x 33.0 mm, 3 parts (1 on the bottom side), 5 nets.

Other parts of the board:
U$1: GHOST

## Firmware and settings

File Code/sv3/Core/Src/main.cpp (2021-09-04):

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
/* Includes ------------------------------------------------------------------*/
#include "main.h"
#include "adc.h"
#include "i2c.h"
#include "tim.h"
#include "gpio.h"

/* USER CODE BEGIN Includes */

#include "system.h"
#include "FDC1004.h"
#include "buzzer.h"

/* USER CODE END Includes */

/* USER CODE BEGIN PD */

#define SAMPLE_RATE 1024

#define INITIAL_SENSITIVITY 2.0

/* USER CODE END PD */


/* USER CODE BEGIN PV */

static const int table_size       = 23;

static const uint16_t F_TABLE[23] = {  800,  900, 1000, 1100, 1200, 1400, 1600, 1700, 1800, 1900,
										 0,    0,    0,
								      2100, 2200, 2300, 2400, 2500, 2600, 2800, 3000, 3100, 3200};

static const uint8_t L_SHOW[23]   =  {0x0F, 0x07, 0x0B, 0x03, 0x05, 0x09, 0x01, 0x02, 0x04, 0x08,
		                              0x00, 0x00, 0x00,
									  0x01, 0x02, 0x04, 0x08, 0x09, 0x0A, 0x0C, 0x0D, 0x0E, 0x0F};

static const uint8_t FULL_LED_SHOW[16]  = {0x00, 0x01, 0x02, 0x03, 0x04, 0x05, 0x06, 0x07,
                                           0x08, 0x09, 0x0A, 0x0B, 0x0C, 0x0D, 0x0E, 0x0F};

static const float VBAT_MAX             = 3.0;              /* max battery voltage 1.5v * 2 [2xAA] */
static const float VBAT_THRESH          = 1.9;              /* minimum battery voltage, boost works down to ~0.9v */
static const float ALPHA                = (15.0 / 100.0);	/* EWMA Alpha value*/
static const float temp_delta 			= 2.0; 				/* temperature delta */

/* USER CODE END PV */

void SystemClock_Config(void);
/* USER CODE BEGIN PFP */

void EWMA(float *ewma, float newVal, float alpha);      /* Exponential weighted moving average function */
void setLedShow(const uint8_t *ptr, uint8_t index);     /* used led map to display cap change, kinda like gray code */
uint8_t LEDShowBat(float vbat);             			/* shows the battery voltage 0% - 100%, 4 steps */
uint8_t getCapValue(FDC1004 *ptr, float *cap);          /* gets cap value in pico F */
uint8_t readButton(uint8_t AB);                         /* returns true if button is pressed */


int calc_index(float value, float baseline, float per, int steps);
void setLedShow(uint8_t val);

/* USER CODE END PFP */

/**
  * @brief  The application entry point.
  * @retval int
  */
int main(void)
{
  /* MCU Configuration--------------------------------------------------------*/

  /* Reset of all peripherals, Initializes the Flash interface and the Systick. */
  HAL_Init();

  /* Configure the system clock */
  SystemClock_Config();

  /* Initialize all configured peripherals */
  MX_GPIO_Init();
  MX_ADC_Init();
  MX_I2C1_Init();
  MX_TIM2_Init();
  /* USER CODE BEGIN 2 */

  int cal_update							= 1;
  int system_update 						= 1; 					//update counter

  float capVal 								= 0; 					//raw cap value
  float smoothCap 							= 0; 					//smoothed cap value
  float base_line 							= 0; 					//Ambient capacitance
  float threshold 							= INITIAL_SENSITIVITY; 	//Sensitivity
  float threshold_percent 					= (threshold / 100.0); 	//Sensitivity %
  float ambiant_temp 						= 0; 					//temperature value


  /*********************************************************************************************/

  /* ----------- LED Awesomeness --------------- */
  setLedShow(FULL_LED_SHOW,  1);  HAL_Delay(100);
  setLedShow(FULL_LED_SHOW,  3);  HAL_Delay(100);
  setLedShow(FULL_LED_SHOW,  7);  HAL_Delay(100);
  setLedShow(FULL_LED_SHOW, 15);  HAL_Delay(100);
  setLedShow(FULL_LED_SHOW,  7);  HAL_Delay(100);
  setLedShow(FULL_LED_SHOW,  3);  HAL_Delay(100);
  setLedShow(FULL_LED_SHOW,  1);  HAL_Delay(100);
  setLedShow(FULL_LED_SHOW,  0);
 /* --------------------------------------------- */

  /* start up ADC */
  system mySys(&hadc);
  if(mySys.init() != 0)
	  Error_Handler();

  /* start up FDC1004 */
  FDC1004 FDC(FDC1004_100HZ, &hi2c1);
  if (FDC.configureMeasurementSingle(0, 0, 0))
      Error_Handler();

  /* init buzzer */
  buzzer buzz;
  if(buzz.init(&htim2, TIM_CHANNEL_1))
      Error_Handler();

  /*------- check vbat before main -------*/
  /* display battery level on led's */
  if(LEDShowBat(mySys.getVBat()) != 0)
      Error_Handler();

  /* fault if vbat < threshold */
  if(mySys.vbatCompare(VBAT_THRESH))
	  Error_Handler();

  /*******************************************/
  /* Get Baseline From FDC1004 */

  /* init baseline with reading != 0 */
  if(getCapValue(&FDC, &base_line))
      Error_Handler();

  /* read 100 samples */
  for(uint8_t i = 0; i < 100; i++) {
      if(getCapValue(&FDC, &capVal))
          Error_Handler();
      EWMA(&base_line, capVal, ALPHA);
  }
  smoothCap = base_line;
  /*********************************************************************/

  /*------- record ambient temp -------*/
  /* after x cycles the chip should be at steady thermal state */
  if(mySys.update() != 0)
	  Error_Handler();
  ambiant_temp = mySys.getTemp();

  /* ready chime */
  setLedShow(FULL_LED_SHOW, 0);
  buzz.chime(4000, 4600, 4000, 50);

  /* USER CODE END 2 */

  /* Infinite loop */
  /* USER CODE BEGIN WHILE */
  while (1)
  {
	  int SEQUENCE_ACTIVE = 0;

      /******************************************************************/
      /******************************************************************/
      /*----------------------------------------------------------------*/
      /* Read Cap Value */
      if(getCapValue(&FDC, &capVal))
          Error_Handler();

      /* smooth value */
      EWMA(&smoothCap, capVal, ALPHA);

      /* check cap value against set */
      // 0,1,2,3,4,5,6,7,8,9,10,11,12,13,14,15,16,17,18,19,20,21,22
      int _index = calc_index(smoothCap, base_line, threshold_percent, table_size);
      if((_index != 10) && (_index != 11) && (_index != 12)) {
    	  SEQUENCE_ACTIVE = 1;
      }

      setLedShow(L_SHOW[_index]);
	  if(buzz.setFreq(F_TABLE[_index]) != 0)
		  Error_Handler();

      /*----------------------------------------------------------------*/
      /******************************************************************/
      /******************************************************************/
      /*----------------------------------------------------------------*/
      /* read buttons */
      //do things 'n' stuff for button 2 [top button]
      if(readButton(2)) {

          threshold += 0.05;
          threshold_percent = (threshold / 100.0);

          if(buzz.chirp(1500, 200))
              Error_Handler();

          //while(readButton(2)); //TODO debug
      }

      //do things 'n' stuff for button 1 [bottom button]
      if(readButton(1)) {

          threshold -= 0.05;
          threshold_percent = (threshold / 100.0);

          if(buzz.chirp(1300, 200))
              Error_Handler();

          //while(readButton(1)); //TODO debug
      }

      /*----------------------------------------------------------------*/
      /******************************************************************/
      /******************************************************************/
      /*----------------------------------------------------------------*/
      /* Read ADC VBAT + RECAL */

	  if(system_update == 0)
	  {
		  if(mySys.update() != 0)
			  Error_Handler();

		  if(mySys.vbatCompare(VBAT_THRESH))
			  Error_Handler();

		  if(SEQUENCE_ACTIVE == 0)
		  {
			  float tmp = mySys.getTemp();
			  if((tmp >= (ambiant_temp + temp_delta)) || (tmp <= (ambiant_temp - temp_delta)))
			  {
				  if(tmp >= (ambiant_temp + temp_delta)) {
					  if(buzz.chime(700, 800, 900, 100)) //chime up
						  Error_Handler();
				  }
				  else {
					  if(buzz.chime(900, 800, 700, 100)) //chime down
						  Error_Handler();
				  }
				  ambiant_temp = tmp;
			  }

			  if(cal_update == 0)
			  {
				  base_line = smoothCap;
			  }
		  }
	  }

	  system_update = (system_update + 1) %  SAMPLE_RATE;    //Increment loop update
	  cal_update    = (cal_update    + 1) % (SAMPLE_RATE*4); //Increment loop update
      /*----------------------------------------------------------------*/

    /* USER CODE END WHILE */

    /* USER CODE BEGIN 3 */
  }
  /* USER CODE END 3 */
}

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
/* USER CODE BEGIN 4 */

/* calc index value based in percent */
int calc_index(float value, float baseline, float per, int steps) {
    int h = 1 - ((steps / 2) + 1);
    for (int i = h; i < steps + h; i++) {
        float b = baseline + (i * per);
        if (value < b)
            return i + (steps + h) - 1;
    }
    return steps - 1;
}

/* get new cap value */
uint8_t getCapValue(FDC1004 *ptr, float *cap) {
    uint8_t ret = 0;
    if(ptr->triggerSingleMeasurement(0, FDC1004_100HZ))
        return 1; //trigger error

      do
      {
        ret = ptr->readCap(0, cap);
        HAL_Delay(1);
      } while(ret == 2); //still processing

      return ret; //all ok
}

/* Exponentially Weighted Moving Average */
void EWMA(float *ewma, float newVal, float alpha) {
    *ewma = (1.0 - alpha) * (*ewma) + alpha * newVal;
}

/* buttons are active low, hardware debounce */
uint8_t readButton(uint8_t AB) {
    if(AB == 1) return !HAL_GPIO_ReadPin(B1_GPIO_Port, B1_Pin);
    if(AB == 2) return !HAL_GPIO_ReadPin(B2_GPIO_Port, B2_Pin);
    return 0;
}

void setLedShow(uint8_t val) {
    GPIO_PinState state;

    state = (val & 0x08) ? GPIO_PIN_RESET : GPIO_PIN_SET;
    HAL_GPIO_WritePin(LED4_GPIO_Port, LED4_Pin, state);

    state = (val & 0x04) ? GPIO_PIN_RESET : GPIO_PIN_SET;
    HAL_GPIO_WritePin(LED1_GPIO_Port, LED1_Pin, state);

    state = (val & 0x02) ? GPIO_PIN_RESET : GPIO_PIN_SET;
    HAL_GPIO_WritePin(LED2_GPIO_Port, LED2_Pin, state);

    state = (val & 0x01) ? GPIO_PIN_RESET : GPIO_PIN_SET;
    HAL_GPIO_WritePin(LED3_GPIO_Port, LED3_Pin, state);
}

void setLedShow(const uint8_t *ptr, uint8_t index) {
    GPIO_PinState state;

    state = (ptr[index] & 0x08) ? GPIO_PIN_RESET : GPIO_PIN_SET;
    HAL_GPIO_WritePin(LED4_GPIO_Port, LED4_Pin, state);

    state = (ptr[index] & 0x04) ? GPIO_PIN_RESET : GPIO_PIN_SET;
    HAL_GPIO_WritePin(LED1_GPIO_Port, LED1_Pin, state);

    state = (ptr[index] & 0x02) ? GPIO_PIN_RESET : GPIO_PIN_SET;
    HAL_GPIO_WritePin(LED2_GPIO_Port, LED2_Pin, state);

    state = (ptr[index] & 0x01) ? GPIO_PIN_RESET : GPIO_PIN_SET;
    HAL_GPIO_WritePin(LED3_GPIO_Port, LED3_Pin, state);
}

uint8_t LEDShowBat(float vbat) {
    float _div = (VBAT_MAX - VBAT_THRESH) / 4.0;

    uint8_t bat_led[5] = { 0, 1, 3, 7, 15 };
    float bat_check[5] = { (float) (VBAT_THRESH + _div * 0.0),
                           (float) (VBAT_THRESH + _div * 1.0),
                           (float) (VBAT_THRESH + _div * 2.0),
                           (float) (VBAT_THRESH + _div * 3.0),
                           (float) (VBAT_THRESH + _div * 4.0)};

    for(int i = 0; i < 5; i++) {
        if((vbat < bat_check[i]) || i == 4) {
            setLedShow(FULL_LED_SHOW, bat_led[i]);
            break;
        }
    }

    HAL_Delay(800);
    return 0;
}

/* USER CODE END 4 */
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


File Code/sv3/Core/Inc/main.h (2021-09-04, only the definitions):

#define LED3_Pin GPIO_PIN_0
#define LED3_GPIO_Port GPIOA
#define LED2_Pin GPIO_PIN_1
#define LED2_GPIO_Port GPIOA
#define LED1_Pin GPIO_PIN_2
#define LED1_GPIO_Port GPIOA
#define LED4_Pin GPIO_PIN_3
#define LED4_GPIO_Port GPIOA
#define BUZZER_Pin GPIO_PIN_5
#define BUZZER_GPIO_Port GPIOA
#define VBAT_IN_Pin GPIO_PIN_1
#define VBAT_IN_GPIO_Port GPIOB
#define B2_Pin GPIO_PIN_3
#define B2_GPIO_Port GPIOB
#define B1_Pin GPIO_PIN_4
#define B1_GPIO_Port GPIOB

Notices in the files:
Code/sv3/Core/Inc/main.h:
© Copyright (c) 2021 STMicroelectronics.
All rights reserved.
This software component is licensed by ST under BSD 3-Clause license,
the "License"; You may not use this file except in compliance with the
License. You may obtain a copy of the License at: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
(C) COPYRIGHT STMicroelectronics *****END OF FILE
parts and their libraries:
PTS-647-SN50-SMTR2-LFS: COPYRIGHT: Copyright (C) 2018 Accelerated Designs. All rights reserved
